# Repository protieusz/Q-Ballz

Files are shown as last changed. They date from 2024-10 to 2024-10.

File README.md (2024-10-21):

# Q-Ballz
Q-Ballz, inspired by an anime with 2 trackballs, 2x CORE-A Mcus, 34 keys, 10 RGBs

# Description
Case design shape was inspired by a Neo Zeon prototype mobile suit, [Qubeley](https://gundam.fandom.com/wiki/AMX-004_Qubeley), one of the underrated MS from the Gundam Zeta series hence the name "Q-Ballz". Q-Ballz uses 2 trackballs as the previous OverLord, where this time the top ball is mouse movement and bottom is scrolling. The size of the custom keeb design is similar size to
Sachiel or the Excelsior.  Nice and compact for office use and wow factor with 10 RGBs on the vents and eyes. There might be some flaws on the "notches" that clips both top and bottom case together. Slight oversight but can make it work
with tiny DIY. Print at your own risk.

**Oct 19, 2024:** Q-Ballz is fully build and functional. All RGBs on both sides are fully working. Thanks to **Drashna Jael're** from fingerpunch discord for helping me out with QMK part and validation of my solder hack. Please see below pic for the hack details.

**Oct 17, 2024:** Q-Ballz fully build but only RIGHT side RGBs are fully working. Voltage and continuity all checks out. So I suspect it might be the QMK code.  Hopefully the QMK code can be fixed.
As for the effect of having set color RGBs for each sides, I tried using transparent colored plastic but it turns out that they are too thin and the RGB lights overpowered it. If someone can program where the RGBs on the right are always constant Blue for the circle vents while the Right eye is Pink, right vents pink while the rest of the LEFT side is pink. Anywayz Qubeley custom keeb mission accomplished.

**Sept 18, 2024:** PCB print will not be printed until October ish since my PMW3360 sensors and SA keycaps have not arrive yet. I am very excited for this build design.

# Disclaimer
This work is a non-commercial fan creation of custom keyboard case and PCB in the shape of Qubeley from the Gundam Zeta series. It is made out of love and respect for the Gundam Zeta series. All rights to Gundam and related content are owned by Bandai Namco Holdings Inc and its associated companies. The images, names, storylines and other elements of Gundam used in this work are the property of their respective copyright holders. Unauthorized commercial use is strictly prohibited. The license of this design reflects not for commercial use. Only the PCB files, QMK source will be open source. The case files due to copyright issues will not be open sourced.

Please print and use the case and PCB at your own risk. QMK code is derived from the QMK documentation and copy over from my OverLord build.

# Full Build
Oct 17, 2024




I had to think outside the box by making the RGBs working on both sides. I edit the config.h RGB split settings to (0, 10) to have all the RGBs sourced from the RIGHT side for all the RGBs.
Then I solder the DOUT from the RIGHT side to the DIN of the LEFT for the RGBs and it worked! Shout out to **Drashna Jael're** from fingerpunch Discord channel for helping me out with QMK part and validation of my solder hack.





















# Renders

Screenshot 2024-09-15 at 11 56 09 PM
Screenshot 2024-09-15 at 11 55 55 PM
Screenshot 2024-09-15 at 11 56 25 PM
Screenshot 2024-09-15 at 11 56 35 PM

Screenshot 2024-09-18 at 3 20 47 PM
Screenshot 2024-09-18 at 3 21 07 PM
Screenshot 2024-09-18 at 3 21 19 PM
Screenshot 2024-09-18 at 3 21 29 PM

Screenshot 2024-09-18 at 9 23 16 AM
Screenshot 2024-09-18 at 9 23 30 AM

Screenshot 2024-09-15 at 4 52 59 PM
Screenshot 2024-09-15 at 4 45 36 PM
Screenshot 2024-09-15 at 3 08 33 PM
Screenshot_2024-09-15_at_12 41 15_PM
Screenshot_2024-09-15_at_12 41 02_PM
Screenshot 2024-09-15 at 11 39 33 AM
Screenshot_2024-09-14_at_1 45 44_PM

# License

</a></p>

You are free to:

Share — copy and redistribute the material in any medium or format

Adapt — remix, transform, and build upon the material

The licensor cannot revoke these freedoms as long as you follow the license terms.
Under the following terms:

Attribution — You must give appropriate credit, provide a link to the license, and indicate if changes were made. You may do so in any reasonable manner, but not in any way that suggests the licensor endorses you or your use.

NonCommercial — You may not use the material for commercial purposes.

ShareAlike — If you remix, transform, or build upon the material, you must distribute your contributions under the same license as the original.

No additional restrictions — You may not apply legal terms or technological measures that legally restrict others from doing anything the license permits.

Q-Ballz by ProtieusKeebs is licensed under [CC BY-NC-SA 4.0](https://creativecommons.org/licenses/by-nc-sa/4.0/?ref=chooser-v1)

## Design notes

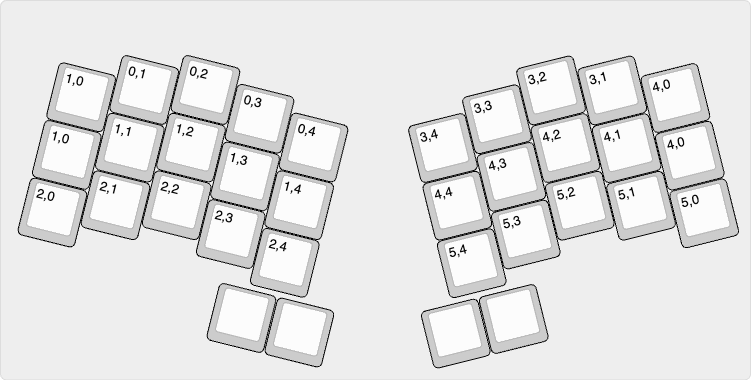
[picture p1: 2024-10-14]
keyboard-layout.png

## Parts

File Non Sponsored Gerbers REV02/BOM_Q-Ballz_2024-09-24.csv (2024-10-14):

ID | Name | Designator | Footprint | Quantity | Manufacturer Part | Manufacturer | Supplier | Supplier Part | Price | link
1 | AP2127K-ADJTRG1 | U8,U8B | SOT-23-5_L3.0-W1.7-P0.95-LS2.8-BR | 2 | AP2127K-ADJTRG1 | DIODES(美台) | LCSC | C96343 | 0.074 | https://lcsc.com/eda_search?q=C96343&%26type=1&ref=editor
2 | 4.7uF | C17,C17B,C19,C19B,C20,C20B | C0402 | 6 | CL05A475MP5NRNC | SAMSUNG(三星) | LCSC | C23733 | 0.005 | https://lcsc.com/eda_search?q=C23733&%26type=1&ref=editor
3 | 100nF | C18,C18B | C0402 | 2 | CL05B104KB54PNC | SAMSUNG(三星) | LCSC | C307331 | 0.005 | https://lcsc.com/eda_search?q=C307331&%26type=1&ref=editor
4 | BAV70-C68978 | D000,D000B,D002,D002B,D004,D004B,D100,D100B,D102,D102B,D104,D104B,D200,D200B,D202,D202B,D204,D204B,D303,D303B | SOT-23-3_L3.0-W1.7-P0.95-LS2.9-BR | 20 | BAV70 | CJ(江苏长电/长晶) | LCSC | C68978 | 0.019 | https://item.szlcsc.com/139341.html
5 | PRTR5V0U2X,215 | D6,D11 | SOT-143_L2.9-W1.3-P1.92-LS2.3-BR | 2 | PRTR5V0U2X,215 | Nexperia(安世) | LCSC | C12333 | 0.09 | https://item.szlcsc.com/280548.html
6 | nSMD050 | F3,F1 | F1206 | 2 | nSMD050 | 台湾陆海 | LCSC | C69688 | 0.037 | https://atta.szlcsc.com/upload/public/pdf/source/20200518/C553934_4CFF0660EAE88BF7A646763F248900C5.pdf
7 | 5.1kΩ | R1,R2,R3,R4 | R0402 | 4 | 0402WGF5101TCE | UNI-ROYAL(厚声) | LCSC | C25905 | 0.001 | https://item.szlcsc.com/323315.html
8 | 10kΩ | R10,R10B,R12,R12B,R13,R13B | R0402 | 6 | 0402WGF1002TCE | UNI-ROYAL(厚声) | LCSC | C25744 | 0.001 | https://lcsc.com/eda_search?q=C25744&%26type=1&ref=editor
9 | 39Ω | R11,R11B | R0402 | 2 | 0402WGJ0390TCE | UNI-ROYAL(厚声) | LCSC | C25164 |  | https://lcsc.com/eda_search?q=C25164&%26type=1&ref=editor
10 | 15kΩ | R14,R14B | R0402 | 2 | 0402WGF1502TCE | UNI-ROYAL(厚声) | LCSC | C25756 | 0.001 | https://lcsc.com/eda_search?q=C25756&%26type=1&ref=editor
11 | RP2040-Core-A | U1L,U1R | RP2040-CORE-A | 2
12 | PMW3360DM-T2QU | U7,U7B | PMW3360DM-T2QU.PACK | 2 | PMW3360DM-T2QU |  |  |  |  | http://www.pixart.com/upload/PMS0058-PMW3360DM-T2QU-NNDS-R1.30-06042016_20160902201411.pdf
13 | TYPE-C-31-M-12 | USBCL,USBCR | USB-C_SMD-TYPE-C-31-M-12 | 2 | TYPE-C-31-M-12 | 韩国韩荣 | LCSC | C165948 | 0.161 | https://so.szlcsc.com/global.html?c=&k=C165948
14 | SK6812MINI-E_C5149201 | U01,U01R,U02,U02R,U03,U03R,U04,U04R,U05,U05R | LED-SMD_L3.2-W2.8-TR | 10 | SK6812MINI-E | 欧思科光电 | LCSC | C5149201 | 0.092 | https://lcsc.com/eda_search?q=C5149201&%26type=1&ref=editor
15 | SN74LVC1T45DCKR | U6L,U6R | SC-70-6_L2.2-W1.3-P0.65-LS2.2-BR | 2 | SN74LVC1T45DCKR | TI(德州仪器) | LCSC | C9382 | 0.119 | https://item.szlcsc.com/51804.html
16 | Switch | K000,K000B,K001,K001B,K002,K002B,K003,K003B,K004,K004B,K100,K100B,K101,K101B,K102,K102B,K103,K103B,K104,K104B,K200,K200B,K201,K201B,K202,K202B,K203,K203B,K204,K204B,K303,K303B,K304,K304B | CHERRY_MX_100_MILLMAX | 34

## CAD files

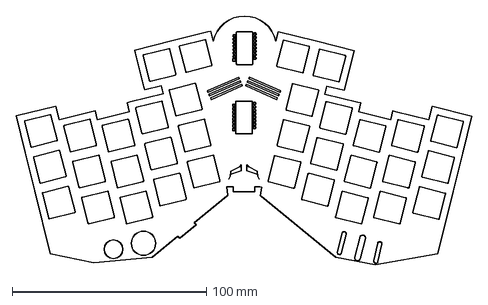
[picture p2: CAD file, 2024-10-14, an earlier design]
Corrective Sensor Positions DXF/QBall PCB Corrected Old Sensor Positions.dxf
234.5 x 128.0 mm

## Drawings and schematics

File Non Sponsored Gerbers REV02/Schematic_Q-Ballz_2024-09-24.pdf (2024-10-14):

## LEFT SIDE RGB RIGHT SIDE RGB

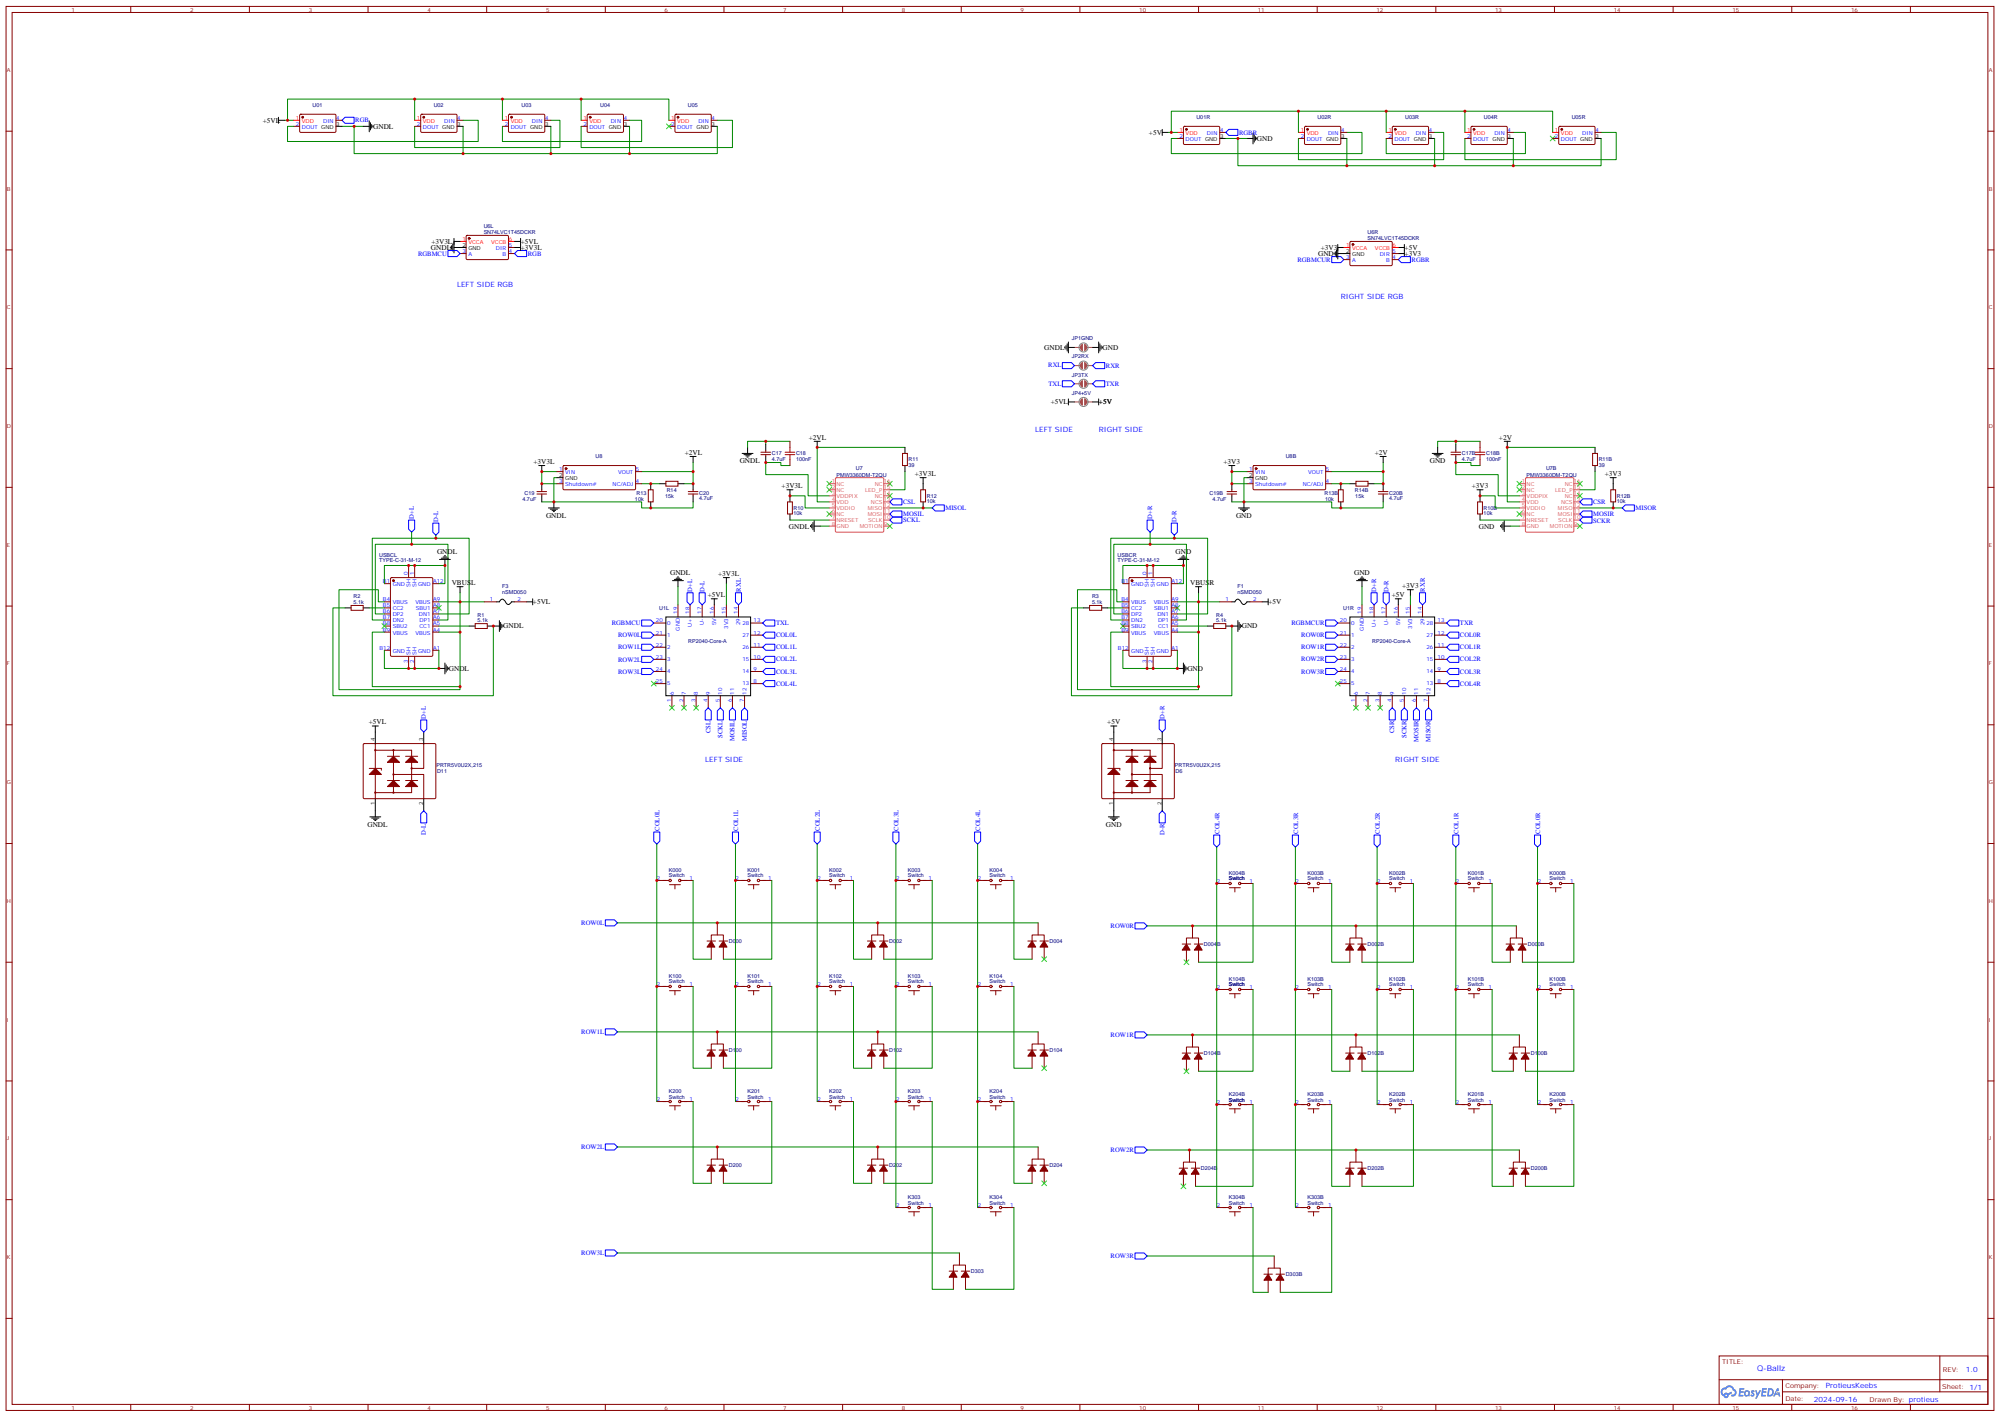
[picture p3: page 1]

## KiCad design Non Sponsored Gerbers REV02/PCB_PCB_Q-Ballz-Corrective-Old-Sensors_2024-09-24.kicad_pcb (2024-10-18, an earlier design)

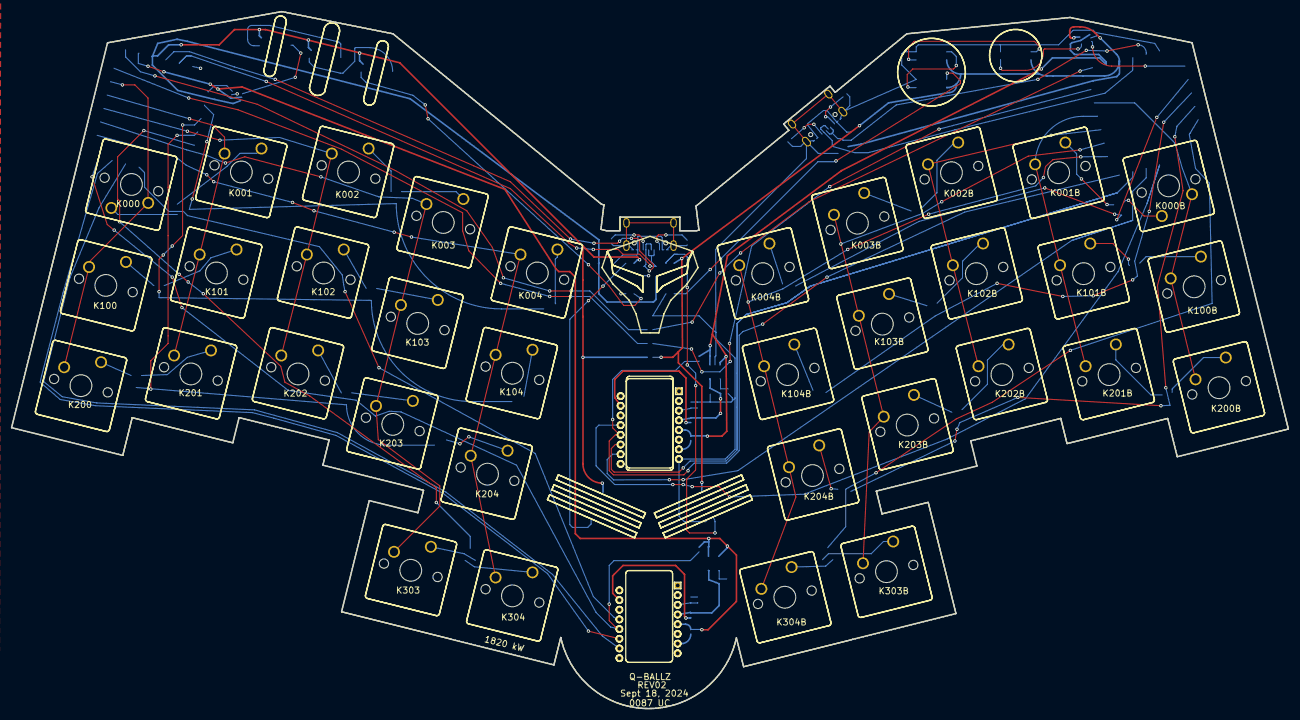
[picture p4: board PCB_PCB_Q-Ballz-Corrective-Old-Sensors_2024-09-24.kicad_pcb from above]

Board: 2 copper layers, 234.5 x 128.0 mm, 104 parts (0 on the bottom side), 102 nets.

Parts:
C17, C17B, C19, C19B, C20, C20B: 4.7uF; C0402
C18, C18B: 100nF; C0402
D000, D000B, D002, D002B, D004, D004B, D100, D100B, D102, D102B, D104, D104B, D200, D200B, D202, D202B, D204, D204B, D303, D303B: BAV70-C68978; SOT-23-3_L3.0-W1.7-P0.95-LS2.9-BR
D6, D11: PRTR5V0U2X,215; SOT-143_L2.9-W1.3-P1.92-LS2.3-BR
F1, F3: nSMD050; F1206
JP1GND, JP2RX, JP3TX, JP4+5V: SOLDER JUMPER PADS; SOLDER BRIDGE JUMPER PADS
K000, K000B, K001, K001B, K002, K002B, K003, K003B, K004, K004B, K100, K100B, K101, K101B, K102, K102B, K103, K103B, K104, K104B, K200, K200B, K201, K201B, K202, K202B, K203, K203B, K204, K204B, K303, K303B, K304, K304B: 100; CHERRY_MX_100_MILLMAX
R1, R2, R3, R4: 5.1kΩ; R0402
R10, R10B, R12, R12B, R13, R13B: 10kΩ; R0402
R11, R11B: 39Ω; R0402
R14, R14B: 15kΩ; R0402
U01, U01R, U02, U02R, U03, U03R, U04, U04R, U05, U05R: SK6812MINI-E_C5149201; LED-SMD_L3.2-W2.8-TR
U1L, U1R: 5; RP2040-CORE-A
U6L, U6R: SN74LVC1T45DCKR; SC-70-6_L2.2-W1.3-P0.65-LS2.2-BR
U7, U7B: PMW3360DM-T2QU; PMW3360DM-T2QU.PACK
U8, U8B: AP2127K-ADJTRG1; SOT-23-5_L3.0-W1.7-P0.95-LS2.8-BR
USBCL: TYPE-C-31-M-12; USB-C_SMD-TYPE-C-31-M-12
USBCR: TYPE-C-31-M-12; USB-C_SMD-TYPE-C-31-M-12

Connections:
+2V: C20B.2, R11B.2, R14B.2, U7B.4, U8B.5
+2VL: C20.2, R11.2, R14.2, U7.4, U8.5
+3V3: C19B.2, R10B.2, R12B.2, U1R.15, U6R.1, U6R.5, U7B.5, U8B.1, U8B.3
+3V3L: C19.2, R10.2, R12.2, U1L.15, U6L.1, U6L.5, U7.5, U8.1, U8.3
+5V: D6.4, F1.2, JP4+5V.2, U01R.1, U1R.16, U02R.1, U03R.1, U04R.1, U05R.1, U6R.6
+5VL: D11.4, F3.2, JP4+5V.1, U01.1, U1L.16, U02.1, U03.1, U04.1, U05.1, U6L.6
C18_1: C17.1, C18.1, U7.3
COL0L: K000.2, K100.2, K200.2, U1L.12
COL0R: K000B.2, K100B.2, K200B.2, U1R.12
COL1L: K001.2, K101.2, K201.2, U1L.11
COL1R: K001B.2, K101B.2, K201B.2, U1R.11
COL2L: K002.2, K102.2, K202.2, U1L.10
COL2R: K002B.2, K102B.2, K202B.2, U1R.10
COL3L: K003.2, K103.2, K203.2, K303.2, U1L.9
COL3R: K003B.2, K103B.2, K203B.2, K303B.2, U1R.9
COL4L: K004.2, K104.2, K204.2, K304.2, U1L.8
COL4R: K004B.2, K104B.2, K204B.2, K304B.2, U1R.8
CSL: U1L.4, U7.13
CSR: U1R.4, U7B.13
D+L: D11.3, U1L.18, USBCL.A6, USBCL.B6
D+R: D6.3, U1R.18, USBCR.A6, USBCR.B6
D-L: D11.2, U1L.17, USBCL.A7, USBCL.B7
D-R: D6.2, U1R.17, USBCR.A7, USBCR.B7
GND: C17B.2, C18B.2, C19B.1, C20B.1, D6.1, JP1GND.2, R3.1, R4.2, R13B.1, U01R.3, U1R.19, U02R.3, U03R.3, U04R.3, U05R.3, U6R.2, U7B.8, U8B.2, USBCR.0, USBCR.1, USBCR.2, USBCR.3, USBCR.A1, USBCR.A12, USBCR.B1, USBCR.B12
GNDL: C17.2, C18.2, C19.1, C20.1, D11.1, JP1GND.1, R1.2, R2.1, R13.1, U01.3, U1L.19, U02.3, U03.3, U04.3, U05.3, U6L.2, U7.8, U8.2, USBCL.0, USBCL.1, USBCL.2, USBCL.3, USBCL.A1, USBCL.A12, USBCL.B1, USBCL.B12
K000B_1: D000B.2, K000B.1
K000_1: D000.1, K000.1
K001B_1: D000B.1, K001B.1
K001_1: D000.2, K001.1
K002B_1: D002B.2, K002B.1
K002_1: D002.1, K002.1
K003B_1: D002B.1, K003B.1
K003_1: D002.2, K003.1
K004B_1: D004B.2, K004B.1
K004_1: D004.1, K004.1
K100B_1: D100B.2, K100B.1
K100_1: D100.1, K100.1
K101B_1: D100B.1, K101B.1
K101_1: D100.2, K101.1
K102B_1: D102B.2, K102B.1
K102_1: D102.1, K102.1
K103B_1: D102B.1, K103B.1
K103_1: D102.2, K103.1
K104B_1: D104B.2, K104B.1
K104_1: D104.1, K104.1
K200B_1: D200B.2, K200B.1
K200_1: D200.1, K200.1
K201B_1: D200B.1, K201B.1
K201_1: D200.2, K201.1
K202B_1: D202B.2, K202B.1
K202_1: D202.1, K202.1
K203B_1: D202B.1, K203B.1
K203_1: D202.2, K203.1
K204B_1: D204B.2, K204B.1
K204_1: D204.1, K204.1
K303B_1: D303B.2, K303B.1
K303_1: D303.1, K303.1
K304B_1: D303B.1, K304B.1
K304_1: D303.2, K304.1
MISOL: R12.1, U1L.7, U7.12
MISOR: R12B.1, U1R.7, U7B.12
MOSIL: U1L.6, U7.11
MOSIR: U1R.6, U7B.11
R3_2: R3.2, USBCR.B5
R4_1: R4.1, USBCR.A5
R10_1: R10.1, U7.7
R11_1: R11.1, U7.15
R14_1: R13.2, R14.1, U8.4
RGB: U01.4, U6L.4
RGBMCU: U1L.20, U6L.3
RGBMCUR: U1R.20, U6R.3
RGBR: U01R.4, U6R.4
ROW0L: D000.3, D002.3, D004.3, U1L.21
ROW0R: D000B.3, D002B.3, D004B.3, U1R.21
ROW1L: D100.3, D102.3, D104.3, U1L.22
ROW1R: D100B.3, D102B.3, D104B.3, U1R.22
ROW2L: D200.3, D202.3, D204.3, U1L.23
ROW2R: D200B.3, D202B.3, D204B.3, U1R.23
ROW3L: D303.3, U1L.24
ROW3R: D303B.3, U1R.24
RXL: JP2RX.1, U1L.14
RXR: JP2RX.2, U1R.14
SCKL: U1L.5, U7.10
SCKR: U1R.5, U7B.10
TXL: JP3TX.1, U1L.13
TXR: JP3TX.2, U1R.13
U01R_2: U01R.2, U02R.4
U02R_2: U02R.2, U03R.4
U02_4: U01.2, U02.4
U03_2: U03.2, U04.4
U03_4: U02.2, U03.4
U04R_4: U03R.2, U04R.4
U04_2: U04.2, U05.4
U05R_4: U04R.2, U05R.4
U7B_3: C17B.1, C18B.1, U7B.3
U7B_7: R10B.1, U7B.7
U7B_15: R11B.1, U7B.15
U8B_4: R13B.2, R14B.1, U8B.4
USBCL_A5: R1.1, USBCL.A5
USBCL_B5: R2.2, USBCL.B5
VBUSL: F3.1, USBCL.A4, USBCL.A9, USBCL.B4, USBCL.B9
VBUSR: F1.1, USBCR.A4, USBCR.A9, USBCR.B4, USBCR.B9

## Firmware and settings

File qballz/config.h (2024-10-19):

// Copyright 2024 
// ProtieusKeebs
// SPDX-License-Identifier: GPL-2.0+

#pragma once

#define RP2040_BOOTLOADER_DOUBLE_TAP_RESET // Activates the double-tap behavior
#define RP2040_BOOTLOADER_DOUBLE_TAP_RESET_TIMEOUT 200U // Timeout window in ms in which the double tap can occur.

#ifdef COMBO_ENABLE
#    define COMBO_COUNT 4
#    define COMBO_TERM 150
#endif


#    define SPLIT_USB_DETECT
#    define USE_SERIAL
#    define SERIAL_USART_FULL_DUPLEX
#    define SERIAL_USART_TX_PIN GP28
#    define SERIAL_USART_RX_PIN GP29
#    define SERIAL_USART_PIN_SWAP
#    define MASTER_LEFT

// SPI
#    define SPI_DRIVER SPID1
#    define SPLIT_POINTING_ENABLE
#    define POINTING_DEVICE_CS_PIN GP9
#    define SPI_SCK_PIN GP10
#    define SPI_MISO_PIN GP12
#    define SPI_MOSI_PIN GP11

// RGB Settings
//#ifdef RGBLIGHT_ENABLE
    #define WS2812_PIO_USE_PIO1
    #define WS2812_DI_PIN GP0
    #define RGBLIGHT_SPLIT
    #define RGBLIGHT_LED_COUNT 10
    #define RGBLED_SPLIT { 0, 10 }
    #define RGBLIGHT_LIMIT_VAL 80
    #define RGBLIGHT_HUE_STEP 10
    #define RGBLIGHT_SAT_STEP 17
    #define RGBLIGHT_VAL_STEP 17

    #define RGBLIGHT_EFFECT_BREATHING
    #define RGBLIGHT_EFFECT_RAINBOW_MOOD
    #define RGBLIGHT_EFFECT_RAINBOW_SWIRL
    #define RGBLIGHT_EFFECT_SNAKE
    #define RGBLIGHT_EFFECT_KNIGHT
    #define RGBLIGHT_EFFECT_CHRISTMAS
    #define RGBLIGHT_EFFECT_STATIC_GRADIENT
    #define RGBLIGHT_EFFECT_TWINKLE
    #define RGBLIGHT_EFFECT_ALTERNATING
//#endif

// PMW3360 settings
//#    define PMW3360_CPI 12000
//#    define PMW3360_CS_DIVISOR 8
//#    define POINTING_DEVICE_TASK_THROTTLE_MS 10
//#    define POINTING_DEVICE_ROTATION_180_RIGHT
#    define POINTING_DEVICE_INVERT_X_RIGHT
#    define POINTING_DEVICE_COMBINED
//#      define POINTING_DEVICE_ROTATION_180_RIGHT
//#      define POINTING_DEVICE_INVERT_X

///#    define POINTING_DEVICE_INVERT_Y
//#    define ROTATIONAL_TRANSFORM_ANGLE 97
//#    define MOUSE_EXTENDED_REPORT


// Mouse key speed and acceleration.
#    undef MOUSEKEY_DELAY
#    define MOUSEKEY_DELAY          0
#    undef MOUSEKEY_INTERVAL
#    define MOUSEKEY_INTERVAL       16
#    undef MOUSEKEY_WHEEL_DELAY
#    define MOUSEKEY_WHEEL_DELAY    0
#    undef MOUSEKEY_MAX_SPEED
#    define MOUSEKEY_MAX_SPEED      6
#    undef MOUSEKEY_TIME_TO_MAX
#    define MOUSEKEY_TIME_TO_MAX    64

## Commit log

2024-09-18 Case files
    [Q Bottom freak.stl, Q Top freak.stl]
2024-09-18 PCB Sketch
    [Q PCB Freak Final Sketch.dxf]
2024-10-14 Gerbers, kicad, etc.
    [BOM_Q-Ballz_2024-09-24.csv, PickAndPlace_PCB_Q-Ballz-Corrective-Old-Sensors_2024-09-24.csv, QBall PCB Corrected Old Sensor Positions.dxf]
2024-10-18 Converted EasyEDA to Kicad files
    [PCB_PCB_Q-Ballz-Corrective-Old-Sensors_2024-09-24.kicad_pcb]
2024-10-19 Working RGBs with soldering hack

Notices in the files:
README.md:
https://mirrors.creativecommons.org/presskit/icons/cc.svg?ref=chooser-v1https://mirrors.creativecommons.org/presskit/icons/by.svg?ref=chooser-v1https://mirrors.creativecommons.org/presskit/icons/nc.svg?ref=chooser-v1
